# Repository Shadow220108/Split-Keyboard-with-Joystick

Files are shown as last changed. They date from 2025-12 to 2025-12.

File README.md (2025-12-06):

# Split-Keyboard-with-Joystick

Its a split keyboard custom designed for most effective use ( for me ) with an integrated joystick ( to be used as cursor) , maximizing productivity and ergonomics  
I am using XIAO NRF58240 rather than ESP32 cause the zmk firmware support is currently experimental/non-existent in the main branch, and the battery life of the keyboard which will be reduced to days rather than months in NRF58240

# HERE IS THE DESIGN OF SPLIT KEYBOARD

CAD

# HERE IS THE CASE ( WHICH WILL BE 3D PRINTED )
CASE

# HERE IS THE PCB DESIGN
PCB

# HERE IS THE LEFT HALF SCHEMATIC

LEFT

# HERE IS THE RIGHT HALF SCHEMATIC

RIGHT

# Firmware
For firmware , i will be using ZMK the files used for them are in the folder i will be flashing it after the build

# BOM 
|ITEM |DESCRIPTION |QUANTITY |UNIT PRICE|TOTAL PRICE|URL |RUNNING TOTAL ( with tax ) |
|---|---|---|---|---|---|---|
| | | | | | | |
|PCB MANUFACTURE |PCB |5(minimum on jlpcb) |3.50$ |17.50$ |https://cart.jlcpcb.com/quote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 |24.50$ |
| | | | | | | |
|Seeed XIAO nRF52840 |MICROCONTROLLER|2 ( one left and one right )|12.50$ |25$ |https://robocraze.com/products/seeed-studio-xiao-nrf52840-development-board-supports-bluetooth-5-0 |49.50$ |
| | | | | | | |
|Kailh MX Hotswap Sockets |SWITCH SOCKETS |Set of 50 |0.10$ |5$ |https://meckeys.com/shop/accessories/keyboard-accessories/key-switches/kailh-hot-swap-socket/ |54.50$ |
| | | | | | | |
|Cherry MX Switches |SWITCH |Set of 50 |0.36$ |18$ |https://meckeys.com/shop/accessories/keyboard-accessories/key-switches/cherry-mx-rgb-switch/ |72.50$ |
| | | | | | | |
|Blank Keycaps 1.0u |KEYCAPS |Set of 50 |0.20$ |10$ |https://meckeys.com/shop/accessories/keyboard-accessories/keycaps/blank-dsa-keycaps-1u/ |82.50$ |
| | | | | | | |
|3.7V LiPo Batteries |BATTERIES |2 ( one left and one right )|1$ |3$ |https://quartzcomponents.com/products/3-7v-1000mah-li-po-rechargeable-battery?variant=44131981295850 |85.10$ |
| | | | | | | |
|1N4148 - Fast Switching Diode SOD-323|DIODES |50 |0.02$ |1.0$ |https://quartzcomponents.com/products/1n4148ws-t4-switching-diode-sod-123-smd-package?variant=45540031627498 |86$ |
| | | | | | | |
|74HC165 |SHIFT REGISTOR |1 |0.2$ |0.2$ |https://quartzcomponents.com/products/74hc165-ic-8-bit-parallel-in-serial-out-shift-register-ic-smd-package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|86$ |
| | | | | | | |
|SK16812 MINI |LED |10 | | | |self sourced |
| | | | | | | |
|Joystick and breakout board |Joystick |1 |0.40$ |0.40$ |https://robu.in/product/joystick-module-ps2-breakout-sensor/ |87.00$ |
| | | | | | | |
| | | | | |TOTAL |90$ approximate with shipping and 3d parts|

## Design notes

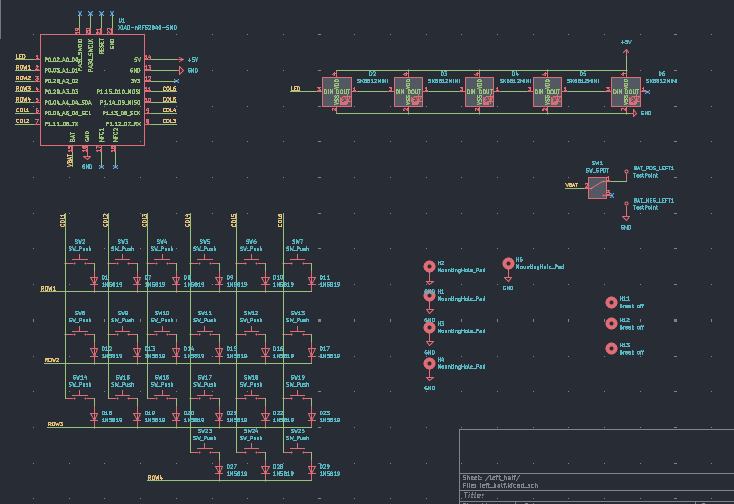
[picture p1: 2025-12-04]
PCB/split_sch_left.png

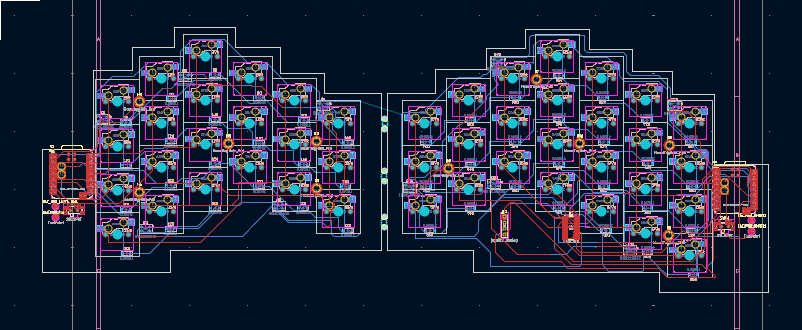
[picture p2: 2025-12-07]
PCB/split_keeb_pcb.png

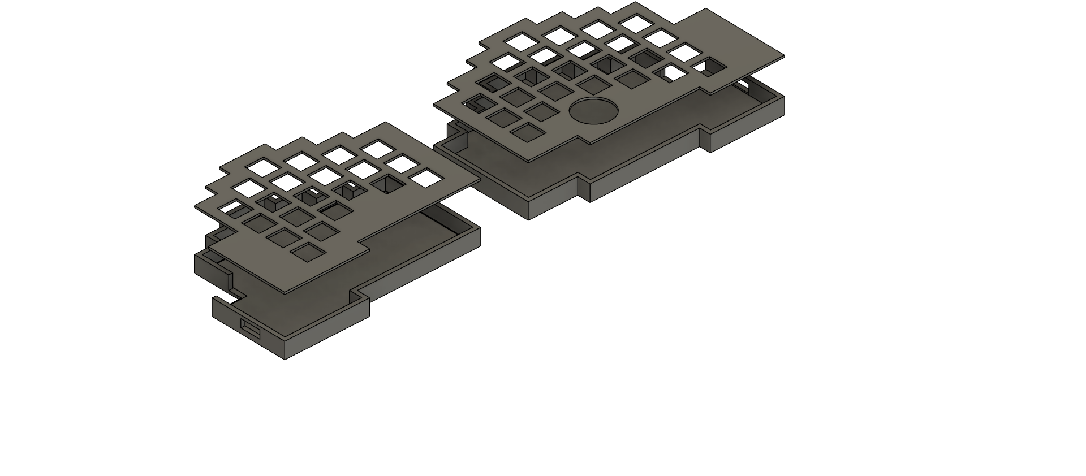
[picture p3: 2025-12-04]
CAD/Split_Keyboard_case.png

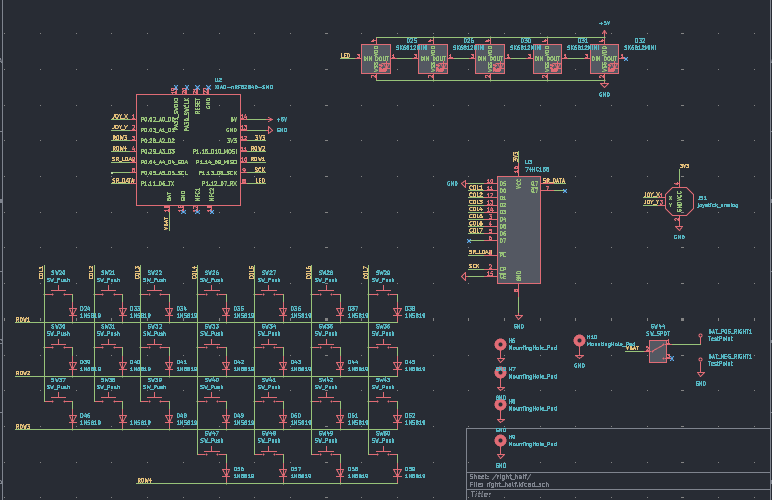
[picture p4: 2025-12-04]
PCB/split_sch_right.png

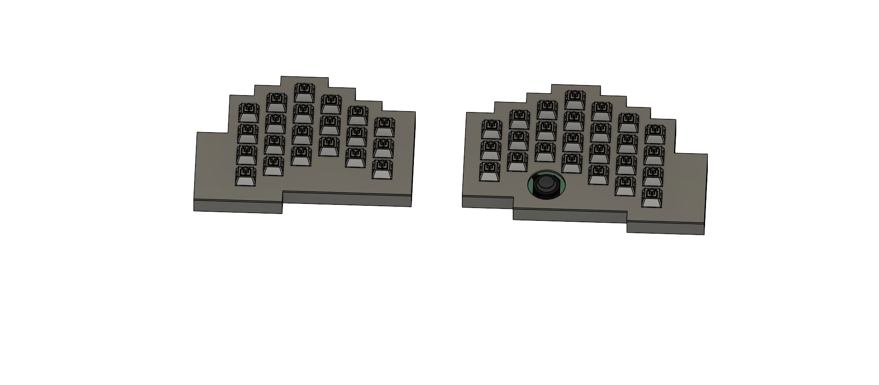
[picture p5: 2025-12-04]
CAD/Split_Keyboard.png

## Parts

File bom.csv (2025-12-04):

ITEM | DESCRIPTION | QUANTITY | UNIT PRICE | TOTAL PRICE | URL | RUNNING TOTAL ( with tax )
PCB MANUFACTURE | PCB | 5(minimum on jlpcb) | 3.50$ | 17.50$ | https://cart.jlcpcb.com/quote?stencilLayer=2&stencilWidth=100&stencilLength=100&stencilCounts=5 | 24.50$
Seeed XIAO nRF52840 | MICROCONTROLLER | 2 ( one left and one right ) | 12.50$ | 25$ | https://robocraze.com/products/seeed-studio-xiao-nrf52840-development-board-supports-bluetooth-5-0 | 49.50$
Kailh MX Hotswap Sockets | SWITCH SOCKETS | Set of 50 | 0.10$ | 5$ | https://meckeys.com/shop/accessories/keyboard-accessories/key-switches/kailh-hot-swap-socket/ | 54.50$
Cherry MX Switches | SWITCH | Set of 50 | 0.36$ | 18$ | https://meckeys.com/shop/accessories/keyboard-accessories/key-switches/cherry-mx-rgb-switch/ | 72.50$
Blank Keycaps 1.0u | KEYCAPS | Set of 50 | 0.20$ | 10$ | https://meckeys.com/shop/accessories/keyboard-accessories/keycaps/blank-dsa-keycaps-1u/ | 82.50$
3.7V LiPo Batteries | BATTERIES | 2 ( one left and one right ) | 2$ | 4$ | https://www.amazon.in/Bhajanlal-Greenery-Rechargeable-Lithium-Batteries/dp/B0CYQ6H8FW | 86.50$
1N4148 - Fast Switching Diode SOD-323 | DIODES | 48 | 0.07$ | 3.50$ | https://www.amazon.in/1N4148-Fast-Switching-Diode-Package/dp/B09NFPM2JF?s=industrial | 90$
74HC165 | SHIFT REGISTOR | 1 | 2$ | 2$ | https://www.amazon.in/gp/product/B0FXWVH5T1?smid=A3612B5TYXK81K&psc=1 | 92$
SK16812 MINI | LED | 10 |  |  |  | self sourced
Joystick and breakout board | Joystick | 1 | 3.50$ | 3.50$ | https://www.amazon.in/Robocraze-Joystick-Breakout-Multi-Directional-High-Precision/dp/B073B647CW | 93.50$
 |  |  |  |  | TOTAL | 100$ approximate with shipping and 3d parts

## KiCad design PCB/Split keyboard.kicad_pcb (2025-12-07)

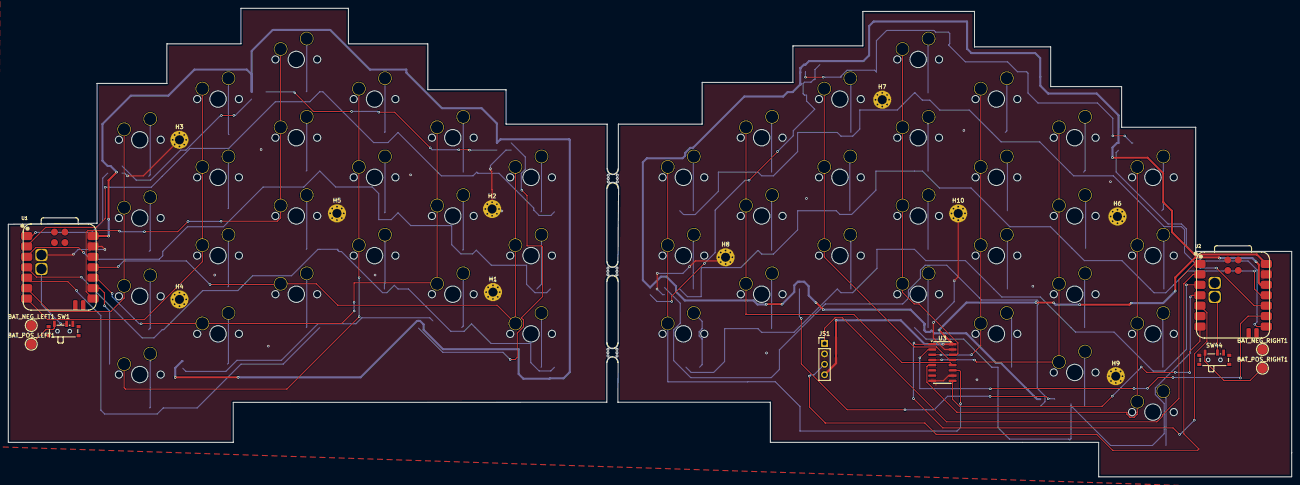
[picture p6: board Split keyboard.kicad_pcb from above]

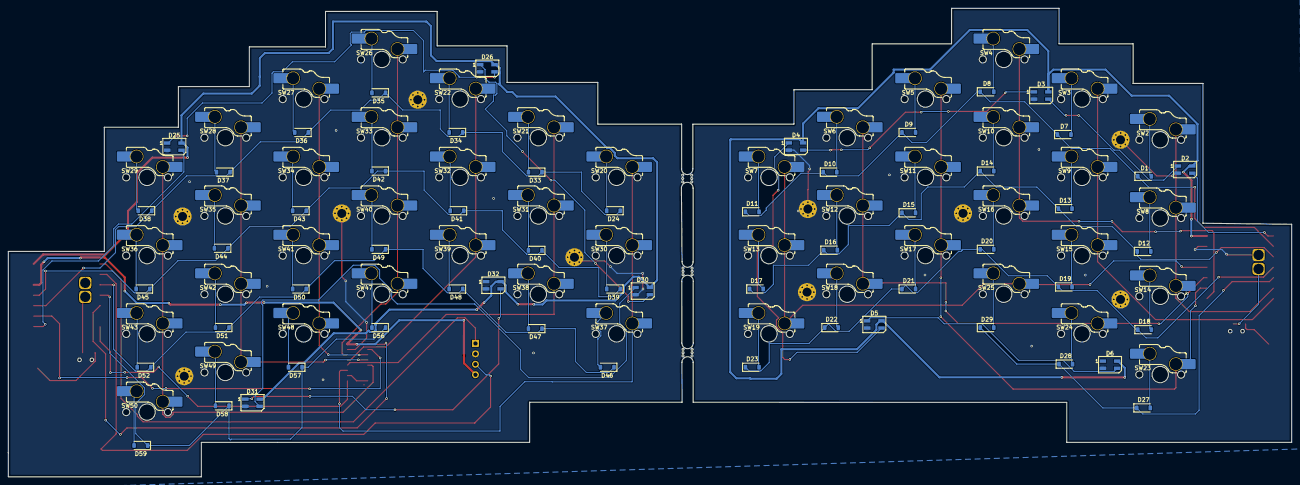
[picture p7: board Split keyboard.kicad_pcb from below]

Board: 2 copper layers, 312.4 x 114.0 mm, 125 parts (102 on the bottom side), 89 nets.

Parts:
BAT_NEG_LEFT1: TestPoint; TestPoint_Pad_D2.5mm
BAT_NEG_RIGHT1: TestPoint; TestPoint_Pad_D2.5mm
BAT_POS_LEFT1: TestPoint; TestPoint_Pad_D2.5mm
BAT_POS_RIGHT1: TestPoint; TestPoint_Pad_D2.5mm
D1, D7, D8, D9, D10, D11, D12, D13, D14, D15, D16, D17, D18, D19, D20, D21, D22, D23, D24, D27, D28, D29, D33, D34, D35, D36, D37, D38, D39, D40, D41, D42, D43, D44, D45, D46, D47, D48, D49, D50, D51, D52, D56, D57, D58, D59: 1N5819; D_SOD-123
D2, D3, D4, D5, D6, D25, D26, D30, D31, D32: SK6812MINI; LED_SK6812MINI_PLCC4_3.5x3.5mm_P1.75mm
H1, H2, H3, H4, H5, H6, H7, H8, H9, H10: MountingHole_Pad; MountingHole_2.2mm_M2_Pad_Via
H11, H12, H13: Break off; mouse-bite-2.54mm-slot
JS1: joystick_analog; PinHeader_1x04_P2.54mm_Vertical
SW1, SW44: SW_SPDT; SW_SPDT_PCM12
SW2, SW3, SW4, SW5, SW6, SW7, SW8, SW9, SW10, SW11, SW12, SW13, SW14, SW15, SW16, SW17, SW18, SW19, SW20, SW21, SW22, SW23, SW24, SW25, SW26, SW27, SW28, SW29, SW30, SW31, SW32, SW33, SW34, SW35, SW36, SW37, SW38, SW39, SW40, SW41, SW42, SW43, SW47, SW48, SW49, SW50: SW_Push; SW_MX_HS_KS-2P02B01-01_1u
U1, U2: XIAO-nRF52840-SMD; modified-XIAO-nRF52840-SMD
U3: 74HC165; SOIC-16_3.9x9.9mm_P1.27mm

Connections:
+5V: D2.4 (VDD), D3.4 (VDD), D4.4 (VDD), D5.4 (VDD), D6.4 (VDD), D25.4 (VDD), D26.4 (VDD), D30.4 (VDD), D31.4 (VDD), D32.4 (VDD), U1.14 (5V), U2.14 (5V)
/left_half/COL1: SW2.1, SW8.1, SW14.1, U1.6 (P0.05_A5_D5_SCL)
/left_half/COL2: SW3.1, SW9.1, SW15.1, U1.7 (P1.11_D6_TX)
/left_half/COL3: SW4.1, SW10.1, SW16.1, U1.8 (P1.12_D7_RX)
/left_half/COL4: SW5.1, SW11.1, SW17.1, SW23.1, U1.9 (P1.13_D8_SCK)
/left_half/COL5: SW6.1, SW12.1, SW18.1, SW24.1, U1.10 (P1.14_D9_MISO)
/left_half/COL6: SW7.1, SW13.1, SW19.1, SW25.1, U1.11 (P1.15_D10_MOSI)
/left_half/LED: D2.3 (DIN), U1.1 (P0.02_A0_D0)
/left_half/ROW1: D1.1 (K), D7.1 (K), D8.1 (K), D9.1 (K), D10.1 (K), D11.1 (K), U1.2 (P0.03_A1_D1)
/left_half/ROW2: D12.1 (K), D13.1 (K), D14.1 (K), D15.1 (K), D16.1 (K), D17.1 (K), U1.3 (P0.28_A2_D2)
/left_half/ROW3: D18.1 (K), D19.1 (K), D20.1 (K), D21.1 (K), D22.1 (K), D23.1 (K), U1.4 (P0.29_A3_D3)
/left_half/ROW4: D27.1 (K), D28.1 (K), D29.1 (K), U1.5 (P0.04_A4_D4_SDA)
/left_half/VBAT: SW1.2 (B), U1.15 (BAT)
/right_half/3V3: JS1.4 (VCC), U2.12 (3V3), U3.16 (VCC)
/right_half/COL1: SW20.1, SW30.1, SW37.1, U3.11 (D0)
/right_half/COL2: SW21.1, SW31.1, SW38.1, U3.12 (D1)
/right_half/COL3: SW22.1, SW32.1, SW39.1, U3.13 (D2)
/right_half/COL4: SW26.1, SW33.1, SW40.1, SW47.1, U3.14 (D3)
/right_half/COL5: SW27.1, SW34.1, SW41.1, SW48.1, U3.3 (D4)
/right_half/COL6: SW28.1, SW35.1, SW42.1, SW49.1, U3.4 (D5)
/right_half/COL7: SW29.1, SW36.1, SW43.1, SW50.1, U3.5 (D6)
/right_half/JOY_X: JS1.1 (X), U2.1 (P0.02_A0_D0)
/right_half/JOY_Y: JS1.3 (Y), U2.2 (P0.03_A1_D1)
/right_half/LED: D25.3 (DIN), U2.8 (P1.12_D7_RX)
/right_half/ROW1: D24.1 (K), D33.1 (K), D34.1 (K), D35.1 (K), D36.1 (K), D37.1 (K), D38.1 (K), U2.10 (P1.14_D9_MISO)
/right_half/ROW2: D39.1 (K), D40.1 (K), D41.1 (K), D42.1 (K), D43.1 (K), D44.1 (K), D45.1 (K), U2.11 (P1.15_D10_MOSI)
/right_half/ROW3: D46.1 (K), D47.1 (K), D48.1 (K), D49.1 (K), D50.1 (K), D51.1 (K), D52.1 (K), U2.3 (P0.28_A2_D2)
/right_half/ROW4: D56.1 (K), D57.1 (K), D58.1 (K), D59.1 (K), U2.4 (P0.29_A3_D3)
/right_half/SCK: U2.9 (P1.13_D8_SCK), U3.2 (CP)
/right_half/SR_DATA: U2.7 (P1.11_D6_TX), U3.9 (Q7)
/right_half/SR_LOAD: U2.5 (P0.04_A4_D4_SDA), U3.1 (~PL)
/right_half/VBAT: SW44.2 (B), U2.15 (BAT)
GND: BAT_NEG_LEFT1.1, BAT_NEG_RIGHT1.1, D2.2 (VSS), D3.2 (VSS), D4.2 (VSS), D5.2 (VSS), D6.2 (VSS), D25.2 (VSS), D26.2 (VSS), D30.2 (VSS), D31.2 (VSS), D32.2 (VSS), H1.1, H2.1, H3.1, H4.1, H5.1, H6.1, H7.1, H8.1, H9.1, H10.1, JS1.2 (GND), U1.13 (GND), U1.16 (GND), U2.13 (GND), U3.8 (GND), U3.10 (DS), U3.15 (~CE)
unnamed: D1.2 (A), SW2.2
unnamed: D2.1 (DOUT), D3.3 (DIN)
unnamed: D3.1 (DOUT), D4.3 (DIN)
unnamed: D4.1 (DOUT), D5.3 (DIN)
unnamed: D5.1 (DOUT), D6.3 (DIN)
unnamed: D7.2 (A), SW3.2
unnamed: D8.2 (A), SW4.2
unnamed: D9.2 (A), SW5.2
unnamed: D10.2 (A), SW6.2
unnamed: D11.2 (A), SW7.2
unnamed: D12.2 (A), SW8.2
unnamed: D13.2 (A), SW9.2
unnamed: D14.2 (A), SW10.2
unnamed: D15.2 (A), SW11.2
unnamed: D16.2 (A), SW12.2
unnamed: D17.2 (A), SW13.2
unnamed: D18.2 (A), SW14.2
unnamed: D19.2 (A), SW15.2
unnamed: D20.2 (A), SW16.2
unnamed: D21.2 (A), SW17.2
unnamed: D22.2 (A), SW18.2
unnamed: D23.2 (A), SW19.2
unnamed: D24.2 (A), SW20.2
unnamed: D25.1 (DOUT), D26.3 (DIN)
unnamed: D26.1 (DOUT), D30.3 (DIN)
unnamed: D27.2 (A), SW23.2
unnamed: D28.2 (A), SW24.2
unnamed: D29.2 (A), SW25.2
unnamed: D30.1 (DOUT), D31.3 (DIN)
unnamed: D31.1 (DOUT), D32.3 (DIN)
unnamed: D33.2 (A), SW21.2
unnamed: D34.2 (A), SW22.2
unnamed: D35.2 (A), SW26.2
unnamed: D36.2 (A), SW27.2
unnamed: D37.2 (A), SW28.2
unnamed: D38.2 (A), SW29.2
unnamed: D39.2 (A), SW30.2
unnamed: D40.2 (A), SW31.2
unnamed: D41.2 (A), SW32.2
unnamed: D42.2 (A), SW33.2
unnamed: D43.2 (A), SW34.2
unnamed: D44.2 (A), SW35.2
unnamed: D45.2 (A), SW36.2
unnamed: D46.2 (A), SW37.2
unnamed: D47.2 (A), SW38.2
unnamed: D48.2 (A), SW39.2
unnamed: D49.2 (A), SW40.2
unnamed: D50.2 (A), SW41.2
unnamed: D51.2 (A), SW42.2
unnamed: D52.2 (A), SW43.2
unnamed: D56.2 (A), SW47.2
unnamed: D57.2 (A), SW48.2
unnamed: D58.2 (A), SW49.2
unnamed: D59.2 (A), SW50.2
unnamed: BAT_POS_LEFT1.1, SW1.1 (A)
unnamed: BAT_POS_RIGHT1.1, SW44.1 (A)

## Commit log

2025-12-04 My updates
    [Split keyboard.kicad_pcb, Split keyboard.kicad_sch, bom.csv]
2025-12-06 Updated Joystick footprint to THT and added BOM
    [Split keyboard.kicad_pcb]
